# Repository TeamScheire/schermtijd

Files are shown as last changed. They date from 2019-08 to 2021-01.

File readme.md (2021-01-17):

Bekijk het lijstje van alle materiaal: [bill of materials](docs/bill-of-materials.csv)

## Download en installeer raspbian

Via [https://www.raspberrypi.org/downloads/raspbian/](https://www.raspberrypi.org/downloads/raspbian)

De lite versie is voldoende.

Instructies om raspbian op een sd-kaart te zetten staan ook op die pagina.

## Configureren van de sd-kaart

Nadat je raspbian op een SD-kaart hebt, moet je deze nog configureren zodat je via ssh over de wifi aan de raspberry pi kan.

Deze stappen voer je dus uit op je eigen computer, met de sd-kaart ingestoken. 

De commando's zijn voor terminal op mac/linux.

### Navigeer naar de folder van de SD-kaart

```
cd /Volumes/boot
```

### SSH aanzetten

In de rootpartitie van de sd-card:

```
touch ssh
```

### Wifi instellen

```
vim wpa_supplicant.conf
```

Vul volgende gegevens in (vervang de xxxx'n door je eigen SSID en wachtwoord) en sla op

```
ctrl_interface=DIR=/var/run/wpa_supplicant GROUP=netdev
network={
    ssid="xxxxx"
    psk="xxxxx"
    key_mgmt=WPA-PSK
}
```

## Configuratie op de raspberry pi

Nadat je raspberry pi is opgestart, ga je ermee verbinden

```
ssh pi@raspberrypi.local
```

Het standaard wachtwoord is *raspberry*

### locale instellen

```
export LC_ALL="en_GB.UTF-8"
```

### Update van het systeem

```
sudo apt-get update && sudo apt-get -y upgrade
```

### Raspi-config

```
sudo raspi-config
```

Kies: 

- Expand Filesystem
- Change hostname: fastfriendsbox
- Set Timezone

reboot

## nodejs + SQLite

Het scorebord en de activiteiten zitten in een SQLite database met een api errond, geschreven in node.js

```
sudo -s
curl -sL https://deb.nodesource.com/setup_11.x | bash -
exit
sudo apt-get install -y nodejs sqlite3
```

meer info op [https://dev.to/bogdaaamn/run-your-nodejs-application-on-a-headless-raspberry-pi-4jnn](https://dev.to/bogdaaamn/run-your-nodejs-application-on-a-headless-raspberry-pi-4jnn)

### ImageMagic voor de verwerking van de avatars

```
sudo apt-get install imagemagick
```

## Activeren/installeren van de api en frontend

In de folder van de nodejs server alle requirements installeren:

```
cd src
npm install
```

De api starten

```
nodejs server.js
```

## automatisch starten en uitvoeren in de achtergrond van de server

```
cd /lib/systemd/system/
sudo nano doosserver.service
```

Vul deze gegevens in:

```
[Unit]
Description=Doos gpio
After=multi-user.target
 
[Service]
Type=simple
ExecStart=/usr/bin/nodejs /home/pi/src/server.js
Restart=on-abort
 
[Install]
WantedBy=multi-user.target
```

En dan dit uitvoeren:

```
sudo chmod 644 /lib/systemd/system/doosserver.service
chmod +x /home/pi/src/server.js
sudo systemctl daemon-reload
sudo systemctl enable doosserver.service
sudo systemctl start doosserver.service
```

De nodejs server draait nu als een service.

## nginx

Het scorebord draait op een webserver op je raspberry pi, hiervoor moet nginx draaien zodat je het vlot via eender welke browser kan bekijken (zolang die op hetzelfde wifi netwerk verbonden is als je raspberry pi).

```
sudo apt-get install -y nginx
```

configureren van je site:

```
sudo rm /etc/nginx/sites-available/default
sudo nano /etc/nginx/sites-available/default

server {
        listen 80;
        listen [::]:80;

        server_name fastfriendsbox.local;

        root /var/www/;
        index index.html;

        location / {
            proxy_pass http://localhost:3000;
            proxy_http_version 1.1;
            proxy_set_header Upgrade $http_upgrade;
            proxy_set_header Connection 'upgrade';
            proxy_set_header Host $host;
            proxy_cache_bypass $http_upgrade;
        }
}
```

(Her)start de webservice hierna:

```
sudo systemctl restart nginx

```

Nu kan je van eender welk toestel dat op hetzelfde netwerk zit als je raspberry pi surfen naar  [http://fastfriendsbox.local](http://fastfriendsbox.local) om het scorebord te zien.

## Thermal printer

Het is deze [https://www.adafruit.com/product/2751](https://www.adafruit.com/product/2751)

Een volledige handleiding en meer bronnen, [https://learn.adafruit.com/mini-thermal-receipt-printer](hier)

### Draadjes aansluiten

- RX van de printer naar TX van de raspi
- TX van de printer naar RX van de raspi
- GND van de printer naar GND van de raspi

De printer stroom geven (minimaal 1.5A 5v - 9v) via het andere adaptor. De printer trekt veel ampère en dit delen met de raspberry pi is geen goed plan ...

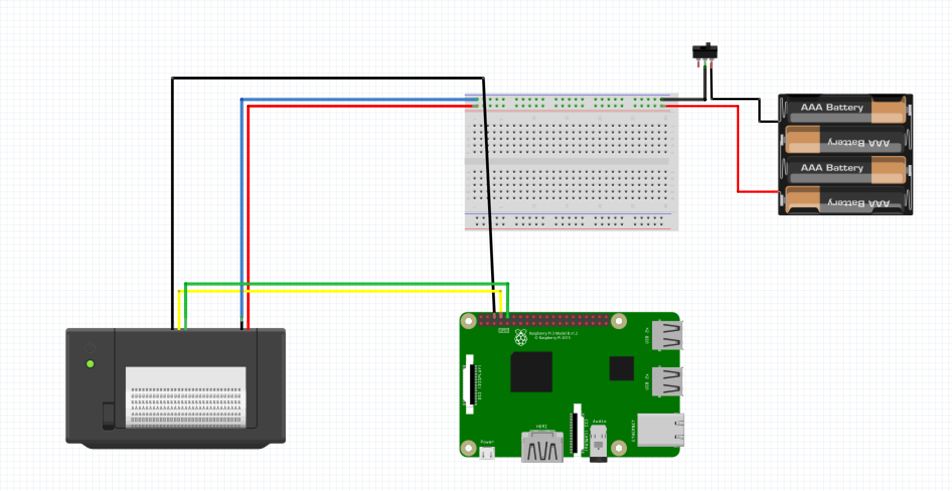
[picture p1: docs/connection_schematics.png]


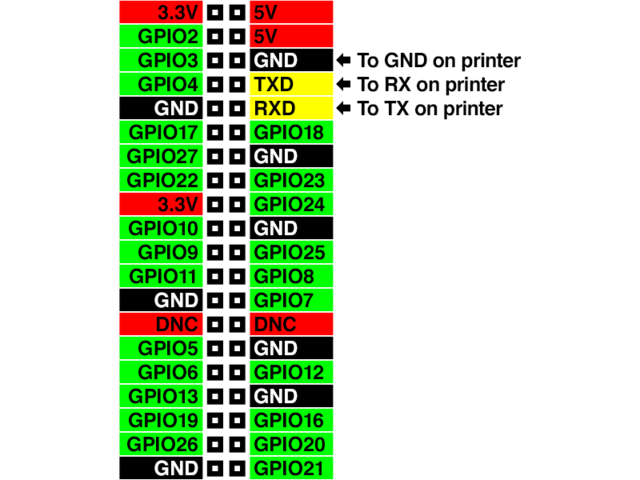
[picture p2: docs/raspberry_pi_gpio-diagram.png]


### activeren over TTL

Eerst configureren zodat we de seriale bus kunnen gebruiken

```
sudo raspi-config
```

Interfacing options > disable the serial console > enable the serial port hardware.

Na reboot, een eerste test:

```
stty -F /dev/ttyS0 9600
echo -e "\\n\\nHallo printertje.\\n\\n\\n" > /dev/ttyS0
```

### repo voor node.js

Om de printer te gebruiken in Node.js, wordt deze library gebruikt: [https://github.com/xseignard/thermalPrinter](https://github.com/xseignard/thermalPrinter).

Via `npm install` heb je deze requirement normaal gezien al geïnstalleerd.

## LED displays

I2C is een protocol waarbij je tot 8 elementen in een bus kan koppelen aan één seriele bus.
Je moet dit protocol eerst activeren op de raspberry pi via raspi-config:

```
sudo raspi-config
```

Daar kies je Interfacing options > I2C > enable (yes)

Voor Python moeten wat paketten/drivers geïnstalleerd worden:

```
sudo apt-get install -y python-smbus i2c-tools build-essential python-dev git python-pil python-pip
git clone https://github.com/adafruit/Adafruit_Python_LED_Backpack.git # voor de 7-segment en de 8x8 matrix
cd Adafruit_Python_LED_Backpack
sudo python setup.py install
cd ..
```

Optioneel (in de uiteindelijke doos zit deze er niet meer in)

```
git clone https://github.com/adafruit/Adafruit_Python_SSD1306.git # voor de oled
cd Adafruit_Python_SSD1306/
sudo python setup.py install

```

Hierna kan je de displays aansluiten en via het volgende commando de adressen checken:

```
sudo i2cdetect -y 1
```

Je krijgt iets in deze aard:

```
pi@schermtijd01:~ $ i2cdetect -y 1
     0  1  2  3  4  5  6  7  8  9  a  b  c  d  e  f
00:          -- -- -- -- -- -- -- -- -- -- -- -- --
10: -- -- -- -- -- -- -- -- -- -- -- -- -- -- -- --
20: -- -- -- -- -- -- -- -- -- -- -- -- -- -- -- --
30: -- -- -- -- -- -- -- -- -- -- -- -- -- -- -- --
40: -- -- -- -- -- -- -- -- -- -- -- -- -- -- -- --
50: -- -- -- -- -- -- -- -- -- -- -- -- -- -- -- --
60: -- -- -- -- -- -- -- -- -- -- -- -- -- -- -- --
70: 70 71 72 -- -- -- -- --
```

Adres 70, 71 en 72 zijn ingebruik

Nog python packet requests installeren om api calls te kunnen doen:

```
pip install requests
```

Starten van python app:

```
python gpio/app.py
```

Stappen staan hier:
[https://learn.adafruit.com/adafruits-raspberry-pi-lesson-4-gpio-setup/configuring-i2c](https://learn.adafruit.com/adafruits-raspberry-pi-lesson-4-gpio-setup/configuring-i2c)

Aansluitingen:
[https://learn.adafruit.com/led-backpack-displays-on-raspberry-pi-and-beaglebone-black/wiring](https://learn.adafruit.com/led-backpack-displays-on-raspberry-pi-and-beaglebone-black/wiring)

python library:
[https://github.com/adafruit/Adafruit_Python_LED_Backpack](https://github.com/adafruit/Adafruit_Python_LED_Backpack)

### Python script as service

```
cd /lib/systemd/system/
sudo nano doos.service
```

Vul deze gegevens in:

```
[Unit]
Description=Doos gpio
After=multi-user.target
 
[Service]
Type=simple
ExecStart=/usr/bin/python /home/pi/gpio/app.py
Restart=on-abort
 
[Install]
WantedBy=multi-user.target
```

En dan dit uitvoeren:

```
sudo chmod 644 /lib/systemd/system/doos.service
chmod +x /home/pi/gpio/app.py
sudo systemctl daemon-reload
sudo systemctl enable doos.service
sudo systemctl start doos.service
```

## PCB voor de doos

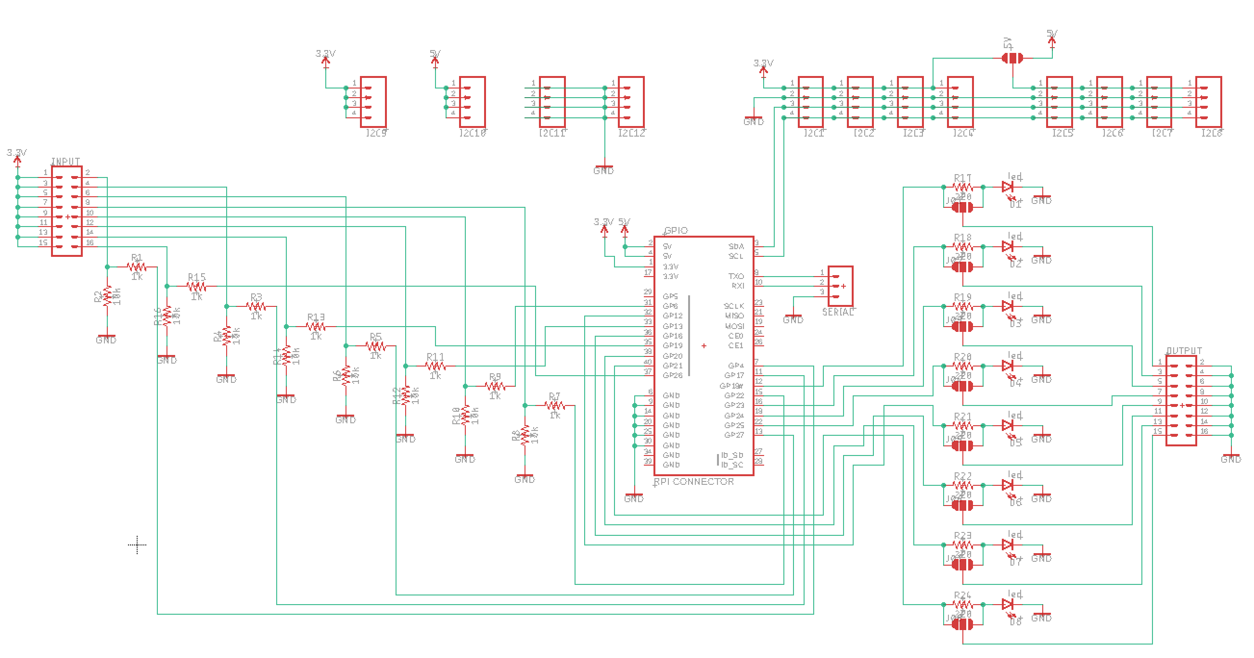
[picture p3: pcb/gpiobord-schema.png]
schema

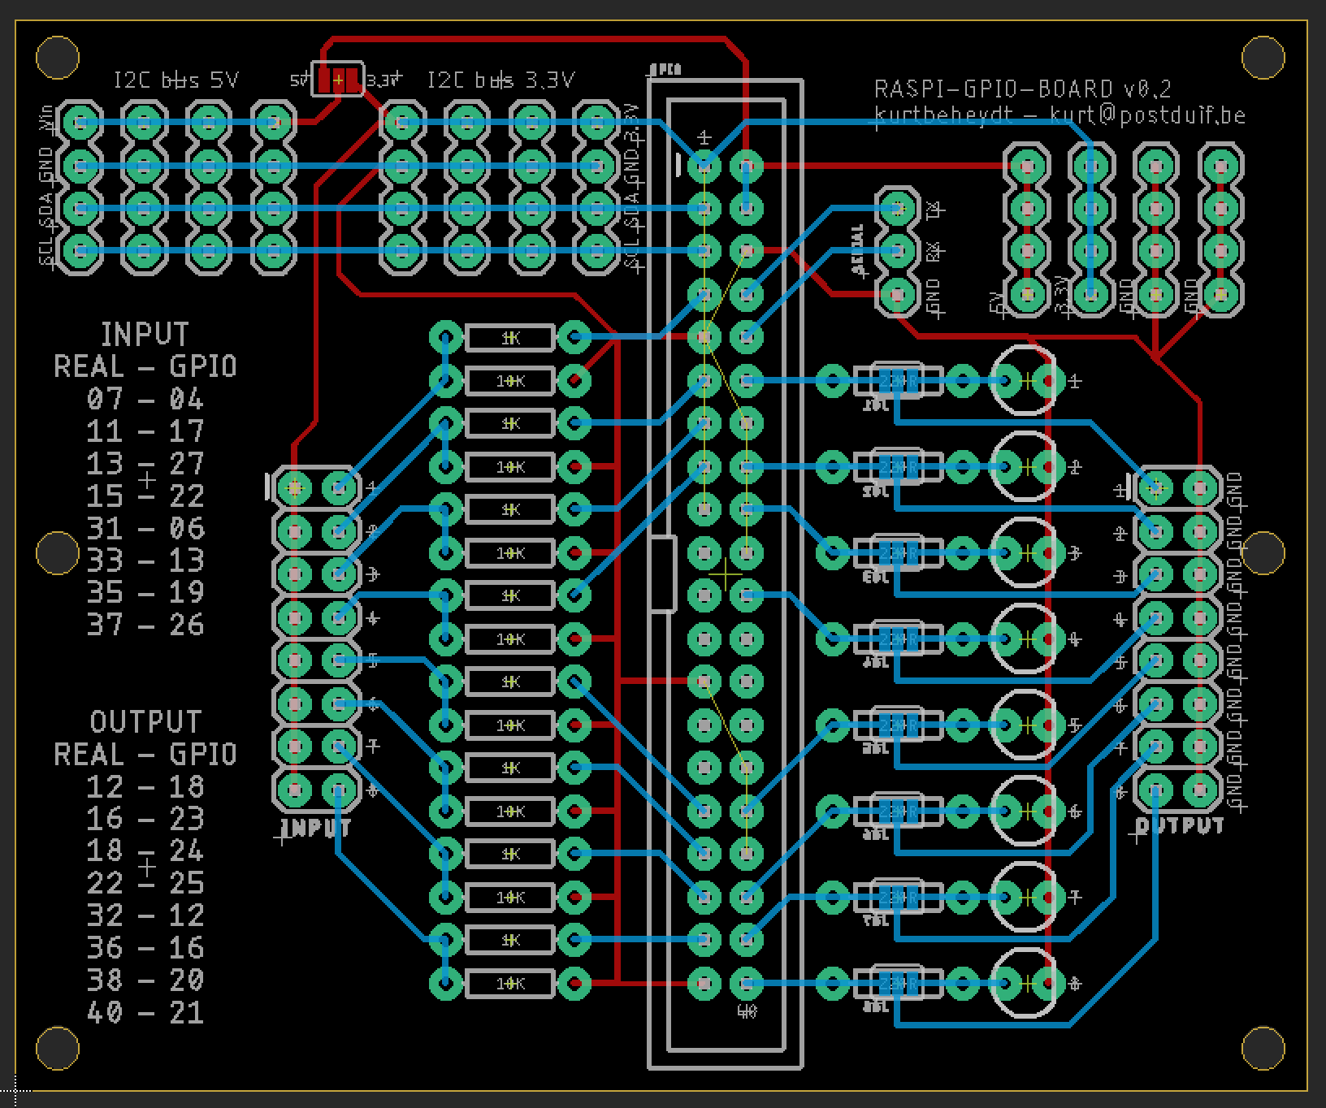
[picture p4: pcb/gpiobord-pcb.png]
pcb


## Extra: raspi als hotspot als geen wifi gevonden wordt
Bron [http://www.raspberryconnect.com/projects/65-raspberrypi-hotspot-accesspoints/158-raspberry-pi-auto-wifi-hotspot-switch-direct-connection](http://www.raspberryconnect.com/projects/65-raspberrypi-hotspot-accesspoints/158-raspberry-pi-auto-wifi-hotspot-switch-direct-connection)

### Installeer de paketten:

```
sudo apt-get install -y hostapd dnsmasq
```

Disable de services bij default:

```
sudo systemctl unmask hostapd
sudo systemctl disable hostapd
sudo systemctl disable dnsmasq
```

### Maak de config file aan:

```
sudo nano /etc/hostapd/hostapd.conf
```

Voeg volgende info in:

```
#2.4GHz setup wifi 80211 b,g,n
interface=wlan0
driver=nl80211
ssid=fastfriendsbox
hw_mode=g
channel=8
wmm_enabled=0
macaddr_acl=0
auth_algs=1
ignore_broadcast_ssid=0
wpa=2
wpa_passphrase=teamscheire
wpa_key_mgmt=WPA-PSK
wpa_pairwise=CCMP TKIP
rsn_pairwise=CCMP
country_code=BE
ieee80211n=1
ieee80211d=1
```

Daarna

```
sudo nano /etc/default/hostapd
```

Verander ```#DAEMON_CONF=""``` in ```DAEMON_CONF="/etc/hostapd/hostapd.conf"```

### Configureer de dns server op de raspberry pi:

```
sudo nano /etc/dnsmasq.conf
```

Vul volgende gegevens in:

```
#AutoHotspot Config
#stop DNSmasq from using resolv.conf
no-resolv
#Interface to use
interface=wlan0
bind-interfaces
dhcp-range=10.0.0.50,10.0.0.150,12h
```
### Configureer de DHCP

```
sudo nano /etc/dhcpcd.conf
```

Voeg onderaan volgende lijn toe:

```
nohook wpa_supplicant
```

### Creëer het hotspot script

```
sudo nano /usr/bin/autohotspot
```

Vul volgende code in:

```
#!/bin/bash
#version 0.95-4-N/HS

#You may share this script on the condition a reference to RaspberryConnect.com 
#must be included in copies or derivatives of this script. 

#A script to switch between a wifi network and a non internet routed Hotspot
#Works at startup or with a seperate timer or manually without a reboot
#Other setup required find out more at
#http://www.raspberryconnect.com

wifidev="wlan0" #device name to use. Default is wlan0.
#use the command: iw dev ,to see wifi interface name 

IFSdef=$IFS
cnt=0
#These four lines capture the wifi networks the RPi is setup to use
wpassid=$(awk '/ssid="/{ print $0 }' /etc/wpa_supplicant/wpa_supplicant.conf | awk -F'ssid=' '{ print $2 }' ORS=',' | sed 's/\"/''/g' | sed 's/,$//')
IFS=","
ssids=($wpassid)
IFS=$IFSdef #reset back to defaults

#Note:If you only want to check for certain SSIDs
#Remove the # in in front of ssids=('mySSID1'.... below and put a # infront of all four lines above
# separated by a space, eg ('mySSID1' 'mySSID2')
#ssids=('mySSID1' 'mySSID2' 'mySSID3')

#Enter the Routers Mac Addresses for hidden SSIDs, seperated by spaces ie 
#( '11:22:33:44:55:66' 'aa:bb:cc:dd:ee:ff' ) 
mac=()

ssidsmac=("${ssids[@]}" "${mac[@]}") #combines ssid and MAC for checking

createAdHocNetwork()
{
    echo "Creating Hotspot"
    ip link set dev "$wifidev" down
    ip a add 10.0.0.5/24 brd + dev "$wifidev"
    ip link set dev "$wifidev" up
    dhcpcd -k "$wifidev" >/dev/null 2>&1
    systemctl start dnsmasq
    systemctl start hostapd
}

KillHotspot()
{
    echo "Shutting Down Hotspot"
    ip link set dev "$wifidev" down
    systemctl stop hostapd
    systemctl stop dnsmasq
    ip addr flush dev "$wifidev"
    ip link set dev "$wifidev" up
    dhcpcd  -n "$wifidev" >/dev/null 2>&1
}

ChkWifiUp()
{
	echo "Checking WiFi connection ok"
        sleep 20 #give time for connection to be completed to router
	if ! wpa_cli -i "$wifidev" status | grep 'ip_address' >/dev/null 2>&1
        then #Failed to connect to wifi (check your wifi settings, password etc)
	       echo 'Wifi failed to connect, falling back to Hotspot.'
               wpa_cli terminate "$wifidev" >/dev/null 2>&1
	       createAdHocNetwork
	fi
}

FindSSID()
{
#Check to see what SSID's and MAC addresses are in range
ssidChk=('NoSSid')
i=0; j=0
until [ $i -eq 1 ] #wait for wifi if busy, usb wifi is slower.
do
        ssidreply=$((iw dev "$wifidev" scan ap-force | egrep "^BSS|SSID:") 2>&1) >/dev/null 2>&1 
        echo "SSid's in range: " $ssidreply
        echo "Device Available Check try " $j
        if (($j >= 10)); then #if busy 10 times goto hotspot
                 echo "Device busy or unavailable 10 times, going to Hotspot"
                 ssidreply=""
                 i=1
	elif echo "$ssidreply" | grep "No such device (-19)" >/dev/null 2>&1; then
                echo "No Device Reported, try " $j
		NoDevice
        elif echo "$ssidreply" | grep "Network is down (-100)" >/dev/null 2>&1 ; then
                echo "Network Not available, trying again" $j
                j=$((j + 1))
                sleep 2
	elif echo "$ssidreplay" | grep "Read-only file system (-30)" >/dev/null 2>&1 ; then
		echo "Temporary Read only file system, trying again"
		j=$((j + 1))
		sleep 2
	elif ! echo "$ssidreply" | grep "resource busy (-16)"  >/dev/null 2>&1 ; then
               echo "Device Available, checking SSid Results"
		i=1
	else #see if device not busy in 2 seconds
                echo "Device unavailable checking again, try " $j
		j=$((j + 1))
		sleep 2
	fi
done

for ssid in "${ssidsmac[@]}"
do
     if (echo "$ssidreply" | grep "$ssid") >/dev/null 2>&1
     then
	      #Valid SSid found, passing to script
              echo "Valid SSID Detected, assesing Wifi status"
              ssidChk=$ssid
              return 0
      else
	      #No Network found, NoSSid issued"
              echo "No SSid found, assessing WiFi status"
              ssidChk='NoSSid'
     fi
done
}

NoDevice()
{
	#if no wifi device,ie usb wifi removed, activate wifi so when it is
	#reconnected wifi to a router will be available
	echo "No wifi device connected"
	wpa_supplicant -B -i "$wifidev" -c /etc/wpa_supplicant/wpa_supplicant.conf >/dev/null 2>&1
	exit 1
}

FindSSID

#Create Hotspot or connect to valid wifi networks
if [ "$ssidChk" != "NoSSid" ] 
then
       if systemctl status hostapd | grep "(running)" >/dev/null 2>&1
       then #hotspot running and ssid in range
              KillHotspot
              echo "Hotspot Deactivated, Bringing Wifi Up"
              wpa_supplicant -B -i "$wifidev" -c /etc/wpa_supplicant/wpa_supplicant.conf >/dev/null 2>&1
              ChkWifiUp
       elif { wpa_cli -i "$wifidev" status | grep 'ip_address'; } >/dev/null 2>&1
       then #Already connected
              echo "Wifi already connected to a network"
       else #ssid exists and no hotspot running connect to wifi network
              echo "Connecting to the WiFi Network"
              wpa_supplicant -B -i "$wifidev" -c /etc/wpa_supplicant/wpa_supplicant.conf >/dev/null 2>&1
              ChkWifiUp
       fi
else #ssid or MAC address not in range
       if systemctl status hostapd | grep "(running)" >/dev/null 2>&1
       then
              echo "Hostspot already active"
       elif { wpa_cli status | grep "$wifidev"; } >/dev/null 2>&1
       then
              echo "Cleaning wifi files and Activating Hotspot"
              wpa_cli terminate >/dev/null 2>&1
              ip addr flush "$wifidev"
              ip link set dev "$wifidev" down
              rm -r /var/run/wpa_supplicant >/dev/null 2>&1
              createAdHocNetwork
       else #"No SSID, activating Hotspot"
              createAdHocNetwork
       fi
fi
```

Maak het script uitvoerbaar:

```
sudo chmod +x /usr/bin/autohotspot
```

### Creëer een service file voor het hotspot script

```
sudo nano /etc/systemd/system/autohotspot.service
```

Vul volgende code in:

```
[Unit]
Description=Automatically generates an internet Hotspot when a valid ssid is not in range
After=multi-user.target
[Service]
Type=oneshot
RemainAfterExit=yes
ExecStart=/usr/bin/autohotspot
[Install]
WantedBy=multi-user.target
```

En activeer de service:

```
sudo systemctl enable autohotspot.service
```

## Meerdere Wifi netwerken instellen

Bewerk deze config file:

```
sudo nano /etc/wpa_supplicant/wpa_supplicant.conf 
```

Vul aan met de SSID en wachtwoorden

```
ctrl_interface=DIR=/var/run/wpa_supplicant GROUP=netdev
update_config=1

network={
    ssid="thuis"
    psk="thuiswachtwoord"
    key_mgmt=WPA-PSK
    id_str="schuis"
}

network={
    ssid="school"
    psk="school-wachtwoord"
    key_mgmt=WPA-PSK
    id_str="school"
}
```

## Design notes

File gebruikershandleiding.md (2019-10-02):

# Fast Friends Box - de handleiding

## Verbinding maken via wifi

Als de fast friends box opgestart is, creëert hij een wifi hotspot.

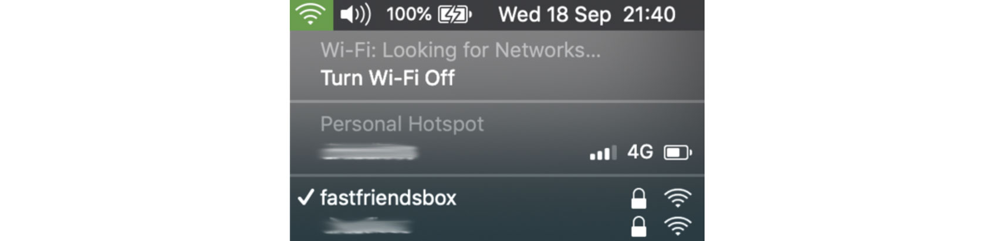
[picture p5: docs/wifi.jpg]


Je kan hier mee verbinden met wachtwoord *teamscheire*.

## Scorebord

Als je met de wifi van de doos verbonden bent, kan je surfen naar het scorebord.

Het adres waar je naar moet surfen is: [http://fastfriendsbox.local](http://fastfriendsbox.local)

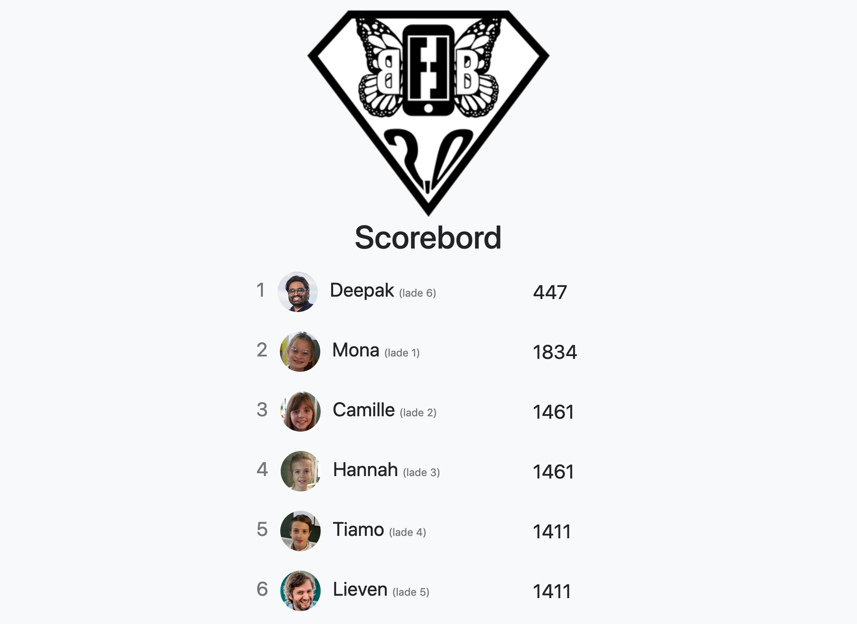
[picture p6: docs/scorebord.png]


## Beheren van de activiteiten

Surf naar [http://fastfriendsbox.local/admin/activiteit.html](http://fastfriendsbox.local/admin/activiteit.html) en je kan activiteiten aanpassen, verwijderen of toevoegen.

Het aantal personen is belangrijk om te bepalen wanneer een activteit door de doos gekozen wordt. Het aantal gsm's dat op dat moment in de doos zit, moet tussen het minimum en maximum aantal liggen van de activiteit.

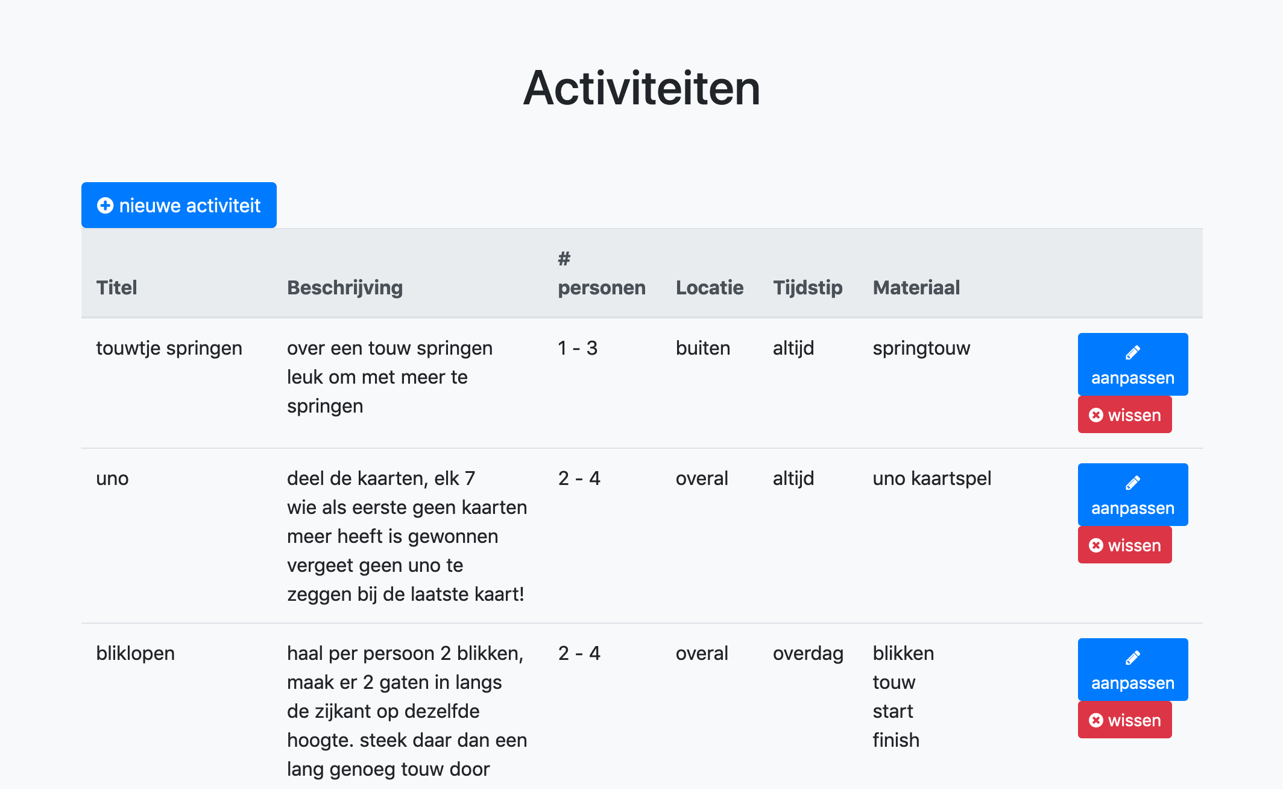
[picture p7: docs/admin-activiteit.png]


## Beheren van de personen (via lades)

Surf naar [http://fastfriendsbox.local/admin/toestel.html](http://fastfriendsbox.local/admin/toestel.html) en je kan de namen van de personen en hun lade aanpassen, de profielfoto's wijzigen en punten aanpassen.

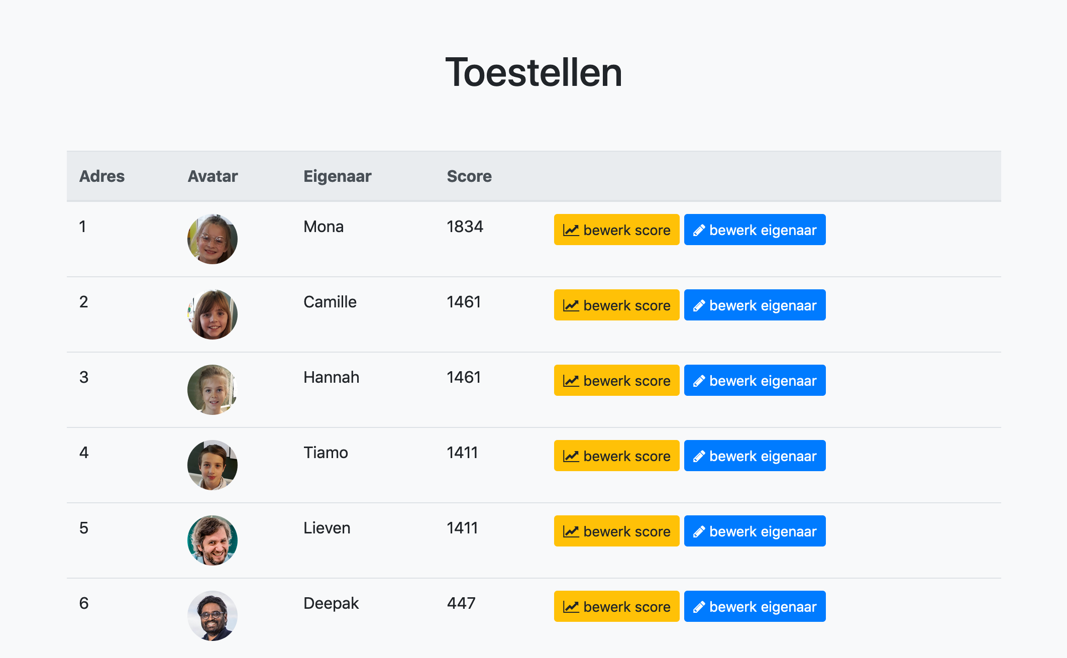
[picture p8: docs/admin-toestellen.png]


### Profielfoto's aanpassen

Klik op de foto van een persoon en je krijgt een scherm om een nieuwe profielfoto te uploaden.

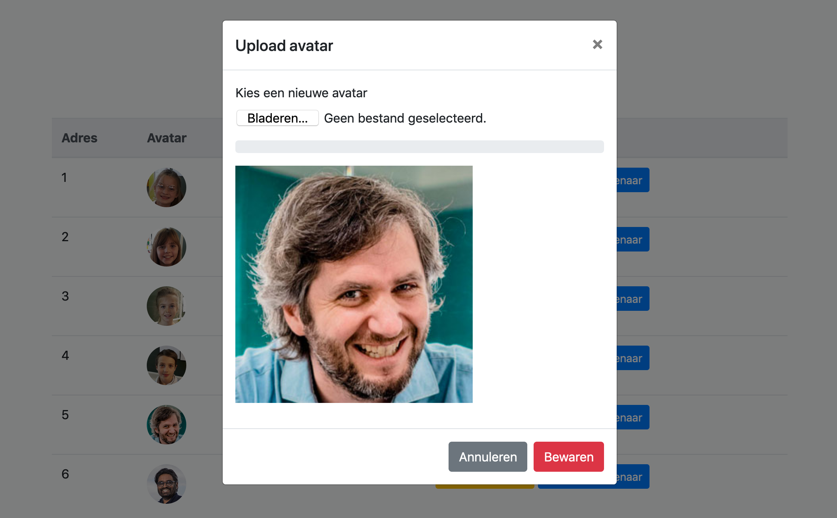
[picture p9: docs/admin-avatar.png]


### Score aanpassen

Klik voor een persoon 'bewerk score'. Je moet nu een extra wachtwoord invullen: *teamscheire* Je krijgt nu een extra scherm waar je punten kan toevoegen, minpunten kan geven of scores kan wissen.

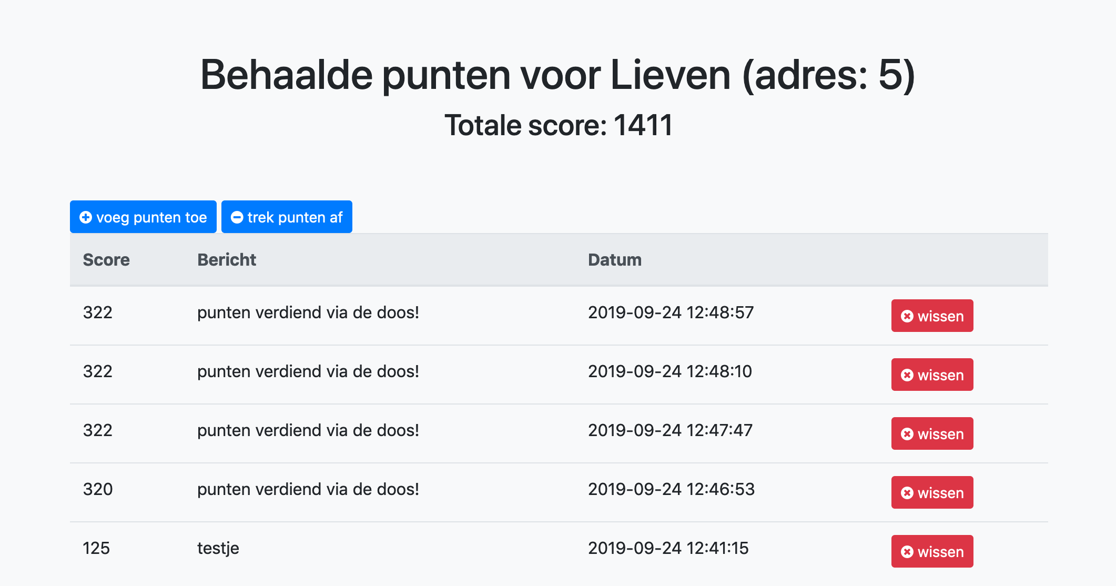
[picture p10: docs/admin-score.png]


## Beheren van de tijdslots

Achter de schermen is er een extra mogelijkheid om per uur te bepalen of er meer of minder punten verdiend kunnen worden als een gsm in de doos zit. Dit gebeurt door per uur een gewicht toe te kennen.

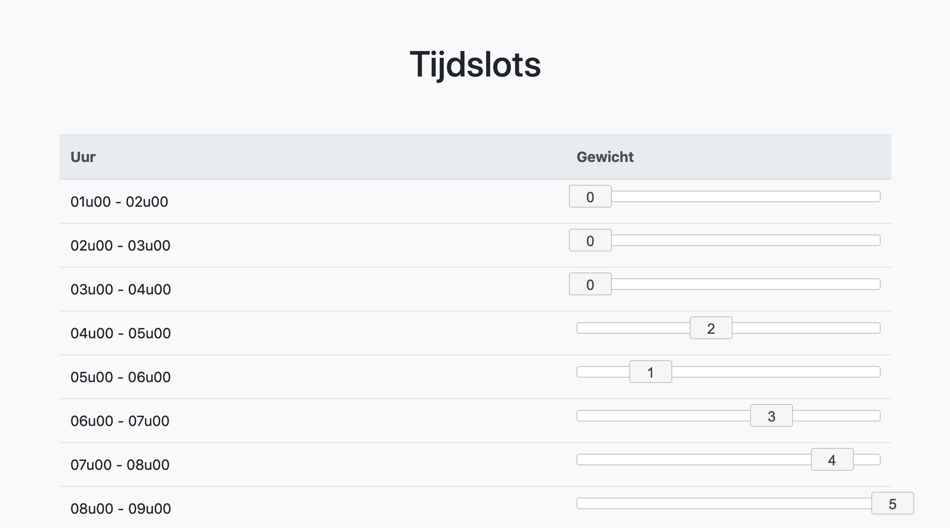
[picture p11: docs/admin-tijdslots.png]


Een gewicht van 0 wil zeggen dat er tijdens dit uur geen punten verdiend worden. Handig bijvoorbeeld voor 's nachts als het niet uit maakt of de gsm in de doos ligt of niet. 

Een gewicht van 5 wil zeggen dat er heel veel punten kunnen verdiend worden tijdens dit uur. Handig voor de piekuren om extra te motiveren om tijdens die uren de gsm in de doos te leggen.

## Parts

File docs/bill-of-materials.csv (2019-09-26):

 | aantal
7 Segment Display Red w/I2C Backpack | 1 | https://www.mouser.be/ProductDetail/Adafruit/1270?qs=sGAEpiMZZMsMyYRRhGMFNq9TrlBKcTqo32ZaxL7MEV4%3D
Adafruit Mini 8x8 Red LED Matrix with Backpack | 2 | https://www.mouser.be/ProductDetail/Adafruit/870
100 V-240 V 6 Port Portable USB Hub | 1 | https://nl.aliexpress.com/item/32596182003.html
Tiny Thermal Receipt Printer | 1 | https://www.mouser.be/ProductDetail/Adafruit/2751
Thermal Paper Roll - 16 long 2.25 | 1 | https://www.mouser.be/ProductDetail/Adafruit/2755
Raspberry Pi 3 model A+ | 1 | https://www.gotron.be/raspberry-pi-3-model-a.html
Industriële voeding Meanwell 50W - 5V / 10A LRS505 | 1 | https://www.gotron.be/industriele-voeding-meanwell-50w-12v-4-2a-lrs505.html
Afdekplaatje 5 polig Meanwell P9,5 | 1 | https://www.gotron.be/afdekplaatje-5-polig-meanwell-p9-5.html
SanDisk Ultra Micro SDHC 16GB | 1 | https://www.bol.com/nl/p/sandisk-ultra-micro-sdhc-16gb-met-adapter/9200000047488161/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
Adafruit Large Arcade LED Red Button | 1 | https://www.mouser.be/ProductDetail/Adafruit/1190
relay + breakout board | 1 | https://nl.aliexpress.com/item/2027291228.html
5v ventilator | 1 | https://www.gotron.be/sunon-ventilator-5vdc-25-x-25-x-10mm-5m-h-16dba.html
Minimicroswitch met hendel | 7 | https://www.gotron.be/minimicroswitch-met-hendel-on-on-5a-125v-3a-250v.html
Sunon Ventilator- 5VDC - 25 x 25 x 10mm -5m3/h - 16dBA | 1 | https://www.gotron.be/sunon-ventilator-5vdc-25-x-25-x-10mm-5m-h-16dba.html
wires with precrimped terminals + crimpconnectors | 1 | https://opencircuit.shop/Product/12605/Wires-with-Pre-crimped-Terminals-50-Piece-Rainbow-Assortment-F-F-24
PCB | 1
Micro-usb kabel | 2
iphone laadkabel | 1
Ledjes 5mm | 6
Ledjes 3mm | 6
weerstand 220Ohm | 12
weerstand 1KOhm | 8
weerstand 10KOhm | 8
female headers (1x20) | 2
male headers (1x8) | 7

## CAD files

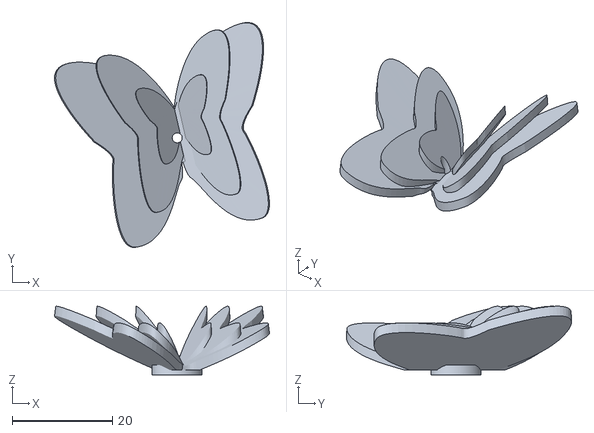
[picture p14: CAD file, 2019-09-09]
doosontwerp/3D-print/vlinder-voetstuk.stl
43.0 x 44.9 x 13.7

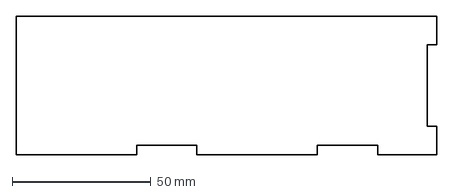
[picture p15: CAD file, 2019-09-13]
doosontwerp/lasercut/3mm-plexi/lade/gsm-schot.dxf
151.5 x 50.0 mm

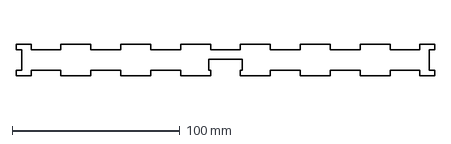
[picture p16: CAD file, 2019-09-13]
doosontwerp/lasercut/3mm-plexi/tussenschot-bovenkant.dxf
250.0 x 19.0 mm

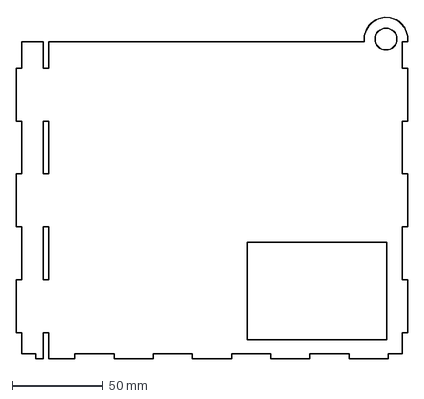
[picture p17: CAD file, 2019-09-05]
doosontwerp/lasercut/3mm/export-rechts.dxf
216.0 x 189.2 mm

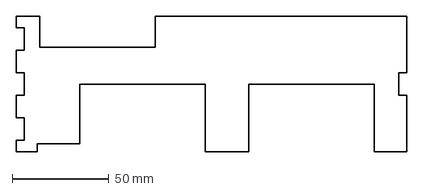
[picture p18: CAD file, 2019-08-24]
doosontwerp/lasercut/4mm/export-tussenschot.dxf
202.0 x 70.0 mm

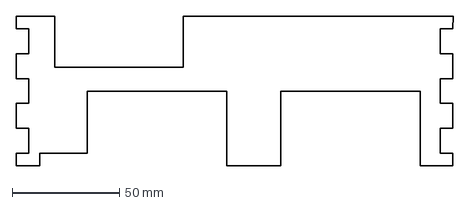
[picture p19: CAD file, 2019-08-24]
doosontwerp/lasercut/6mm/export-tussenschot.dxf
204.0 x 70.0 mm

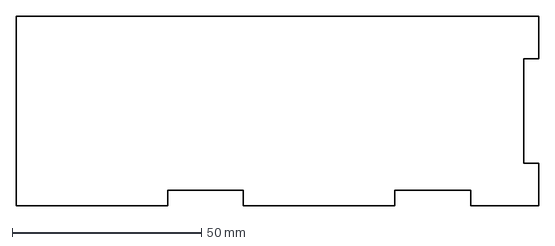
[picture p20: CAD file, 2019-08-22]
doosontwerp/lasercut/export-gsm-schot copy 4.dxf
138.0 x 50.0 mm

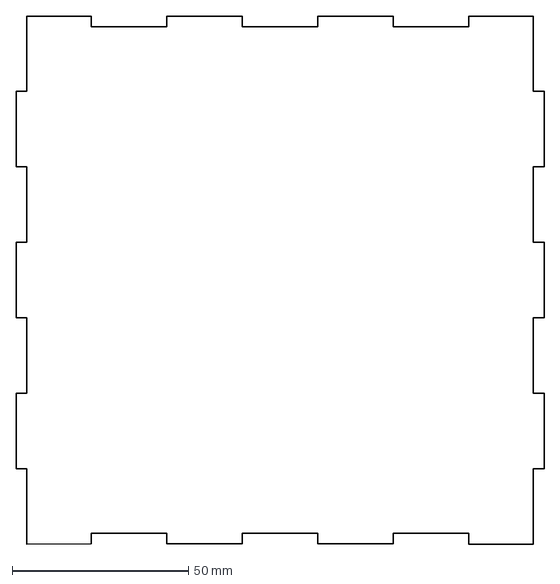
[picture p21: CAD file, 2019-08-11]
lasercut-files/demodoos/export-bottom.dxf
150.0 x 150.0 mm

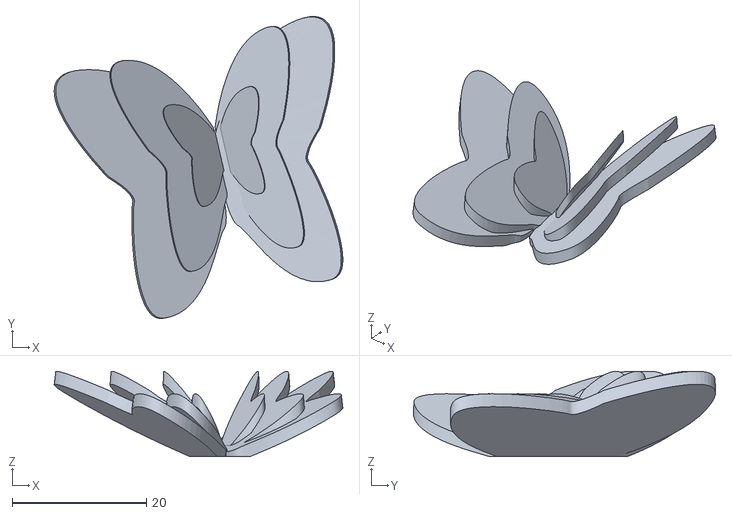
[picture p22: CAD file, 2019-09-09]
doosontwerp/3D-print/vlinder.stl
43.0 x 44.9 x 12.7

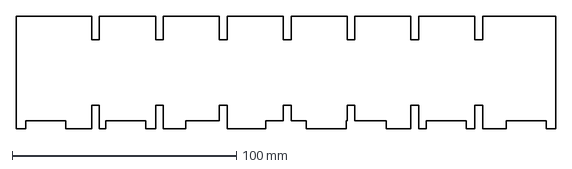
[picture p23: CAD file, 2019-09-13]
doosontwerp/lasercut/3mm-plexi/lade/valse-achterkant.dxf
241.0 x 50.0 mm

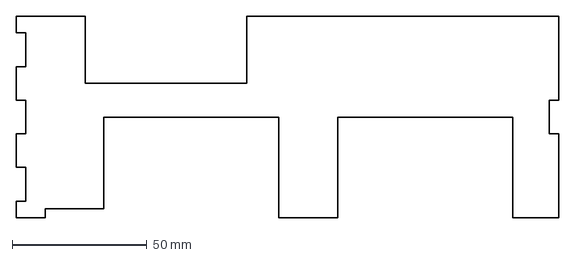
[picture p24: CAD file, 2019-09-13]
doosontwerp/lasercut/3mm-plexi/tussenschot.dxf
201.5 x 75.0 mm

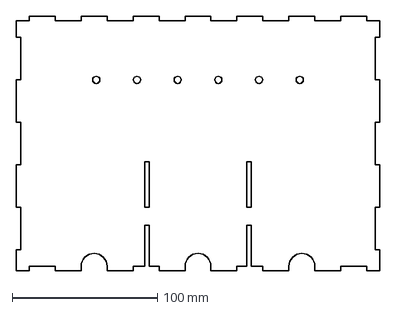
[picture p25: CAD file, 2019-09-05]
doosontwerp/lasercut/3mm/export-tussenschot-voorkant.dxf
250.0 x 175.0 mm

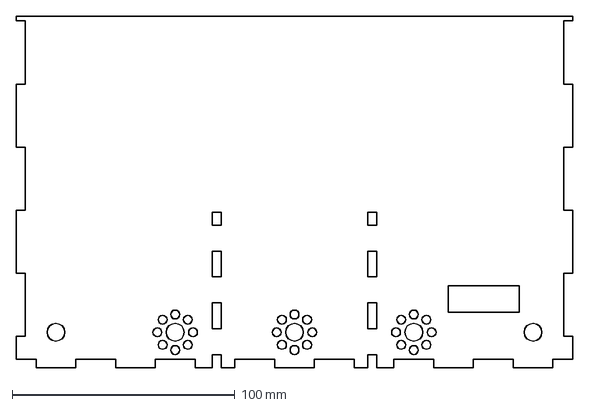
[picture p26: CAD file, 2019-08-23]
doosontwerp/lasercut/4mm/export-achterkant.dxf
250.0 x 158.0 mm

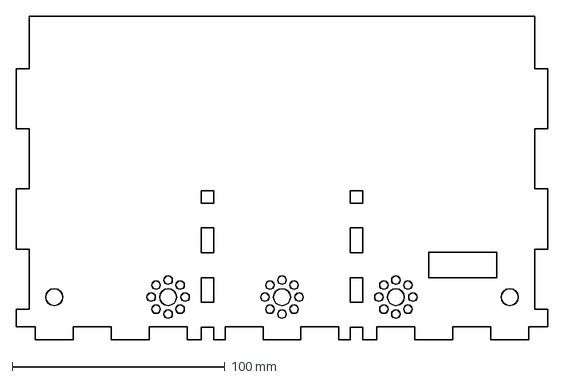
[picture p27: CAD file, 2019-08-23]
doosontwerp/lasercut/6mm/export-achterkant.dxf
250.0 x 152.0 mm

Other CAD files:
doosontwerp/3D-print/gsmslot-verkleiner-4mm.stl
doosontwerp/lasercut/3mm-plexi/lade/valse-bodem.dxf
doosontwerp/lasercut/3mm-plexi/voorkant.dxf
doosontwerp/3D-print/gsmslot-verkleiner-2mm.stl
doosontwerp/3D-print/gsmslot-verkleiner-3mm.stl
doosontwerp/3D-print/microswitch-houder.stl
doosontwerp/3D-print/washer.stl
doosontwerp/lasercut/3mm-plexi/achterkant.dxf
doosontwerp/lasercut/3mm-plexi/bodem.dxf
doosontwerp/lasercut/3mm-plexi/links.dxf
doosontwerp/lasercut/3mm-plexi/rechts.dxf
doosontwerp/lasercut/3mm-plexi/top.dxf
doosontwerp/lasercut/3mm-plexi/tussenschot-voorkant.dxf
doosontwerp/lasercut/3mm/export-achterkant.dxf
doosontwerp/lasercut/3mm/export-bodem.dxf
doosontwerp/lasercut/3mm/export-gsm-schot.dxf
doosontwerp/lasercut/3mm/export-gsm-slot.dxf
doosontwerp/lasercut/3mm/export-links.dxf
doosontwerp/lasercut/3mm/export-top.dxf
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

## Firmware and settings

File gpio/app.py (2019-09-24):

#!/usr/bin/env python

import sched, time, datetime, requests, subprocess
from threading import Thread
import RPi.GPIO as GPIO
from Adafruit_LED_Backpack import SevenSegment
from Adafruit_LED_Backpack import Matrix8x8
import Adafruit_GPIO.SPI as SPI

from PIL import Image
from PIL import ImageDraw
from PIL import ImageFont

displayMode = True

try:
	print('testing I2C')

	# 8X8 led matrix
	matrixRight = Matrix8x8.Matrix8x8()
	matrixRight.begin()
	print('matrixRight loaded')
	matrixLeft = Matrix8x8.Matrix8x8(address=0x72)
	matrixLeft.begin()
	print('matrixLeft loaded')
	# 7-segment display
	display = SevenSegment.SevenSegment(address=0x71, busnum=1)
	display.begin()
	print('SevenSegment loaded')

except Exception as e:
	print('error loading I2C')
	print(e)
	displayMode = False

gsmSlots = [
	# buttonpin, ledpin, toestelnumber
	[13, 16, 1],
	[6, 12, 2],
	[22, 25, 3],
	[27, 24, 4],
	[17, 23, 5],
	[4, 18, 6],
]

doosButton = [19, 20] # gpio poort waarop de knop van het deksel van de doos aangesloten is, status led
activiteitButton = [26, 21] # gpio poort waarop de knop om een activiteit af te drukken op aangesloten is, status led

statusDoosDeksel = 0 # 0 = open, 1 = gesloten
statusPrinting = 0
activeButtons = []
points = 0
currentHour = -1
currentScoreWeight = 0
lastScoreMillis = 0
scoreStartMillis = 0
scoreDelay = 1
stateEyes = 'sad'
stopEyes = False

apiurl = 'http://localhost:3000/api/'
debugMode = 0
eyesThread = False
scoreThread = False

def setup():
	global eyesThread, scoreThread, scoreStartMillis, currentHour
	GPIO.setmode(GPIO.BCM)

	for slot in gsmSlots:
		GPIO.setup(slot[0], GPIO.IN)
		GPIO.setup(slot[1], GPIO.OUT)

	GPIO.add_event_detect(gsmSlots[0][0], GPIO.BOTH, callback = lambda x: handleButton(gsmSlots[0][0], gsmSlots[0][1], gsmSlots[0][2]))
	GPIO.add_event_detect(gsmSlots[1][0], GPIO.BOTH, callback = lambda x: handleButton(gsmSlots[1][0], gsmSlots[1][1], gsmSlots[1][2]))
	GPIO.add_event_detect(gsmSlots[2][0], GPIO.BOTH, callback = lambda x: handleButton(gsmSlots[2][0], gsmSlots[2][1], gsmSlots[2][2]))
	GPIO.add_event_detect(gsmSlots[3][0], GPIO.BOTH, callback = lambda x: handleButton(gsmSlots[3][0], gsmSlots[3][1], gsmSlots[3][2]))
	GPIO.add_event_detect(gsmSlots[4][0], GPIO.BOTH, callback = lambda x: handleButton(gsmSlots[4][0], gsmSlots[4][1], gsmSlots[4][2]))
	GPIO.add_event_detect(gsmSlots[5][0], GPIO.BOTH, callback = lambda x: handleButton(gsmSlots[5][0], gsmSlots[5][1], gsmSlots[5][2]))

	GPIO.setup(doosButton[0], GPIO.IN)
	GPIO.setup(doosButton[1], GPIO.OUT)
	GPIO.add_event_detect(doosButton[0], GPIO.BOTH, callback = lambda x: handledoosButton(doosButton[0], doosButton[1]))

	GPIO.setup(activiteitButton[0], GPIO.IN)
	GPIO.setup(activiteitButton[1], GPIO.OUT)
	GPIO.add_event_detect(activiteitButton[0], GPIO.BOTH, callback = lambda x: handleActiviteitButton(activiteitButton[0], activiteitButton[1]))
	
	eyesThread = Thread(target=animateEyes, args=(stateEyes,))
	eyesThread.start()
	
	resetPoints()

	print('loaded ...')

def millis():
	return int(round(time.time() * 1000))

def animateEyes(dummyvar):
	global stateEyes, stopEyes
	if (displayMode):
		eyesTemplates = {
			'heart': {
				'delay': 250,
				'loop': 2,
				'nextTemplate': 'beatingHeart',
				'stopPrevious': True,
				'sequences': [
					[
						['00000000', '00000000', '00000000', '00011000', '00011000', '00000000', '00000000', '00000000'],
						['00000000', '00000000', '00000000', '00011000', '00011000', '00000000', '00000000', '00000000']
					],
					[
						['00000000', '00000000', '00011000', '00111100', '00111100', '00011000', '00000000', '00000000'],
						['00000000', '00000000', '00011000', '00111100', '00111100', '00011000', '00000000', '00000000']						
					],
					[
						['00000000', '01100110', '11111111', '11111111', '01111110', '00111100', '00011000', '00000000'],
						['00000000', '01100110', '11111111', '11111111', '01111110', '00111100', '00011000', '00000000']
					]
				]
			},
 			'beatingHeart': {
				'delay': 300,
				'loop': 2,
                'nextTemplate': 'happy',
				'stopPrevious': False,
				'sequences': [
					[
						['00000000', '00000000', '00011000', '00111100', '00111100', '00011000', '00000000', '00000000'],
						['00000000', '00000000', '00011000', '00111100', '00111100', '00011000', '00000000', '00000000']						
					],
					[
						['00000000', '01100110', '11111111', '11111111', '01111110', '00111100', '00011000', '00000000'],
						['00000000', '01100110', '11111111', '11111111', '01111110', '00111100', '00011000', '00000000']
					]
				]
			},
 			'happy': {
				'delay': 1500,
				'loop': 0,
                'nextTemplate': 'happy',
				'stopPrevious': False,
				'sequences': [
					[
						['00111000', '01111100', '11111110', '11000110', '11000110', '11111110', '01111100', '00000000'],
						['00011100', '00111110', '01111111', '01100011', '01100011', '01111111', '00111110', '00000000']
					],
					[
						['00000000', '00111000', '01111100', '11111110', '11000110', '11000110', '11111110', '01111100'],
						['00000000', '00011100', '00111110', '01111111', '01100011', '01100011', '01111111', '00111110']
					]
				]
			},     
 			'sad': {
				'delay': 6000,
				'loop': 0,
                'nextTemplate': 'sad',
				'stopPrevious': True,
				'sequences': [
					[
						['00000000', '00000000', '11111110', '11111110', '11000110', '01111100', '00000000', '00000000'],
						['00000000', '00000000', '01111111', '01111111', '01100011', '00111110', '00000000', '00000000']
					],
						[
						['00000000', '00000000', '00000000', '11111110', '11111110', '11000110', '01111100', '00000000'],
						['00000000', '00000000', '00000000', '01111111', '01111111', '01100011', '00111110', '00000000']
					]
				]
			},     
		}

		currentStateEyes = ''
        eyesSequence = 0
        lastMillis = 0
        delay = 0
        currentLoop = 0

        while True:
			if stopEyes:
				print('stopped eye animation')
				matrixLeft.clear()
				matrixLeft.write_display()
				matrixRight.clear()
				matrixRight.write_display()
				break

			if (currentStateEyes):
				try:
					if ((lastMillis + delay) < millis()):
						lastMillis = millis()
						eyes = eyesTemplates[currentStateEyes]['sequences'][eyesSequence]

						matrixLeft.clear()
						matrixRight.clear()
						for x in range(8):
							for y in range(8):
								matrixLeft.set_pixel(x, y, int(eyes[0][x][y]))
								matrixRight.set_pixel(x, y, int(eyes[1][x][y]))
						matrixLeft.write_display()
						matrixRight.write_display()

						sequenceCount = len(eyesTemplates[stateEyes]['sequences'])
						eyesSequence = eyesSequence + 1

						if (eyesSequence >= sequenceCount):
							currentLoop = currentLoop + 1
							eyesSequence = 0
							if ((eyesTemplates[stateEyes]['loop'] > 0) and (currentLoop >= eyesTemplates[stateEyes]['loop'])):
								stateEyes = eyesTemplates[stateEyes]['nextTemplate']
				except:
					print('ledmatrix print error')

			if (stateEyes != currentStateEyes):
				print('new state: ' + stateEyes)
				delay = eyesTemplates[stateEyes]['delay']
				currentStateEyes = stateEyes
				eyesSequence = 0
				currentLoop = 0
				if (eyesTemplates[stateEyes]['stopPrevious']):
					lastMillis = 0

def writeEyes():
	global stateEyes
	if (len(activeButtons) > 0):
		stateEyes = 'heart'
	else:
		stateEyes = 'sad'

def writePoints():
	global points, statusDoosDeksel

	if (displayMode):
		try:
			display.clear()
			if (statusDoosDeksel != 1):
				display.print_number_str('----')
			else:
				display.print_float(points, decimal_digits = 0)
			display.set_colon(False)
			display.write_display()
		except:
			print('writepoints display print error')

def resetPoints():
	global points
	points = 0
	writePoints()

def getScoreHour():
	global currentHour, currentScoreWeight
	now = datetime.datetime.now()
	if (currentHour != now.hour):
		url = apiurl + 'tijdslot/{}'.format(now.hour)
		print('api call: ' + url)
		try:
			response = requests.get(url)
			responsedata = response.json()
			print(responsedata['data'])
			currentHour = now.hour
			currentScoreWeight = responsedata['data']['gewicht']
		except:
			print('api not ready')
	
	return currentScoreWeight

def incrementPoints():
	global points, activeButtons, currentScoreWeight, lastScoreMillis, scoreStartMillis

	scoreDelay = (20 - (2 * currentScoreWeight)) * 1000

	if ((millis() - scoreStartMillis) < 30000):
		scoreDelay = scoreDelay / 2
	if ((millis() - scoreStartMillis) < 20000):
		scoreDelay = scoreDelay / 3
	if ((millis() - scoreStartMillis) < 10000):
		if ((scoreDelay / 4) > 1000):
			scoreDelay = (scoreDelay / 4)
		else:
			scoreDelay = 1000
	if ((millis() - scoreStartMillis) < 5000):
		scoreDelay = 1000

	#print('current millis: ' + str(millis()))
	#print('current scoreStartMillis: ' + str(scoreStartMillis))
	#print('current score delay: ' + str(scoreDelay))

	if (lastScoreMillis + scoreDelay < millis()):
		lastScoreMillis = millis()
		points = points + len(activeButtons)
		#print(points)
		writePoints()

def calculatePoints():
	global activeButtons, statusDoosDeksel
	if ((statusDoosDeksel == 1) and (len(activeButtons) > 0)):
		getScoreHour()
		incrementPoints()
	else:
		resetPoints()

def handleButton(buttonPin, ledPin, toestelNumber):
	global activeButtons, debugMode
	time.sleep(.1)
	buttonStatus = GPIO.input(buttonPin)
	print('gedrukt op pin: ' + str(buttonPin) + ' - status: ' + str(buttonStatus))
	GPIO.output(ledPin, buttonStatus)

	if (buttonStatus):
		if toestelNumber not in activeButtons:
			activeButtons.append(toestelNumber)
	else:
		if toestelNumber in activeButtons:
			activeButtons.remove(toestelNumber)
	writeEyes()

def handledoosButton(buttonPin, ledPin):
	global statusDoosDeksel, points, scoreStartMillis, activeButtons
	time.sleep(.1)
	buttonStatus = GPIO.input(buttonPin)
	GPIO.output(ledPin, buttonStatus)
	print('deksel van de doos is veranderd: ' + str(buttonPin) + ' - status: ' + str(buttonStatus))

	# als van open naar dicht
	if ((statusDoosDeksel == 0) and (buttonStatus == 1)):
		print('Doos is toe gegaan')
		print(activeButtons)
		scoreStartMillis = millis()
		writePoints()

	# als van dicht naar open
	if ((statusDoosDeksel == 1) and (buttonStatus == 0)):
		print('Doos is open gegaan')
		print(activeButtons)
		statusDoosDeksel = buttonStatus
		writePoints()

		if (points > 0):
			data = {
				'score': points,
				'bericht': 'punten verdiend via de doos!',
				'adressen': activeButtons
			}
			url = apiurl + 'toestel/doosscore'
			print('api call: ' + url)
			response = requests.post(url, data=data)
			print(response.json())

	statusDoosDeksel = buttonStatus

def printActiviteit(activeButtons, ledPin):
	global statusPrinting
	print('printing ...')
	cmd = "/usr/bin/nodejs /home/pi/src/print.js {}".format(len(activeButtons))
	result = subprocess.check_output(cmd, shell = True )
	print('done printing')
	statusPrinting = 0
	GPIO.output(ledPin, statusPrinting)

def handleActiviteitButton(buttonPin, ledPin):
	global statusPrinting, activeButtons, statusDoosDeksel
	time.sleep(.1)
	buttonStatus = GPIO.input(buttonPin)
	print('Activiteitknop is ingedrukt: ' + str(buttonPin) + ' - status: ' + str(buttonStatus))
	if ((statusPrinting == 0) and (buttonStatus == 1) and (len(activeButtons) >= 1) and (statusDoosDeksel == 1)):
		print('action to print')
		statusPrinting = 1
		GPIO.output(ledPin, statusPrinting)
		printThread = Thread(target=printActiviteit, args=(activeButtons, ledPin,))
		printThread.start()

def loop():
	while True:
		calculatePoints()
		time.sleep(.5)

def destroy():
	global stopEyes, displayMode, gsmSlots
	try:
		stopEyes = True
		for slot in gsmSlots:
			GPIO.setup(slot[1], GPIO.LOW)
		GPIO.setup(doosButton[1], GPIO.LOW)
		GPIO.setup(activiteitButton[1], GPIO.LOW)
	
		if (displayMode):
			display.clear()
			display.write_display()

		displayMode = False

		GPIO.cleanup()
	except:
		print('I2C error while stopping')

if __name__ == '__main__':
	setup()
	try:
		loop()

	except (KeyboardInterrupt):
		destroy()

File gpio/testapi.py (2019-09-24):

#!/usr/bin/env python

import sched, time, datetime, requests, subprocess

statusDoosDeksel = 0 # 0 = open, 1 = gesloten
statusPrinting = 0
activeButtons = [1]
points = 0
currentHour = -1
currentScoreWeight = 0
lastScoreMillis = 0
scoreStartMillis = 0
scoreDelay = 1
stateEyes = 'sad'
stopEyes = False

apiurl = 'http://localhost:3000/api/'

def setup():
	global scoreStartMillis, currentHour
	currentHour = getScoreHour()
	scoreStartMillis = millis()
	#resetPoints()

	print('loaded ...')

def millis():
	return int(round(time.time() * 1000))

def getScoreHour():
	global currentHour, currentScoreWeight
	now = datetime.datetime.now()
	if (currentHour != now.hour):
		currentHour = now.hour
		url = apiurl + 'tijdslot/{}'.format(currentHour)
		print('api call: ' + url)
		response = requests.get(url)
		responsedata = response.json()
		currentScoreWeight = responsedata['data']['gewicht']
	return currentHour

def incrementPoints():
	global points, activeButtons, currentScoreWeight, lastScoreMillis, scoreStartMillis

	scoreDelay = (20 - (2 * currentScoreWeight)) * 1000

	if ((millis() - scoreStartMillis) < 30000):
		scoreDelay = scoreDelay / 2
	if ((millis() - scoreStartMillis) < 10000):
		scoreDelay = scoreDelay / 3
	if ((millis() - scoreStartMillis) < 5000):
		scoreDelay = 1000

	print('current score delay: ' + str(scoreDelay))

	if (lastScoreMillis + scoreDelay < millis()):
		lastScoreMillis = millis()
		points = points + len(activeButtons)
		print(points)
	    #writePoints()

def doeScore():
	global activeButtons
	activeButtons.append(2)
	activeButtons.append(3)
	activeButtons.append(4)
	activeButtons.append(5)
	activeButtons.append(6)
	print(activeButtons)
	data = {
		'score': 322,
		'bericht': 'punten verdiend via de doos!',
		'adressen': activeButtons
	}
	url = apiurl + 'toestel/doosscore'
	print('api call: ' + url)
	response = requests.post(url, data=data)
	print(response.json())

def loop():
	while True:
		getScoreHour()
		incrementPoints()
		time.sleep(.5)

def destroy():
    print('destroyed')

if __name__ == '__main__':
	setup()
	try:
		doeScore()

	except (KeyboardInterrupt):
		destroy()

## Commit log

2019-08-04 uitleg aansluitingen en setup raspberry pi
    [connection_schematics.fzz]
2019-08-11 demodoos lasercut files
    [export-back.dxf, export-bottom.dxf, export-front.dxf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]
2019-08-13 eerste versie van python app met één button en displays
2019-08-13 offline includes + bugfix
    [printertest.js]
2019-08-15 doos software klaar voor meerdere slots, button voor deksel
2019-08-15 aansluiting op raspi: pcb + schematics
    [connection_schematics.fzz]
2019-08-15 skeleton voor printen van random activiteit
2019-08-17 twee 8x8 matrices voor de ogen + test voor extra oled display
2019-08-19 lasercutfiles - plaatdikte 4mm
    [export-achterkant.dxf, export-bodem.dxf, export-gsm-schot copy 2.dxf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]
2019-08-19 omwisseling van de oogjes
2019-08-20 optimalisatie van de tray in functie van de voetjes voor de schakelaars
    [export-tussenschot copy.dxf, export-tussenschot.dxf, export-valse-bodem.dxf]
2019-08-20 kleine aanpassingen aan ontwerp
    [export-achterkant.dxf, export-back.dxf, export-bodem.dxf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]
2019-08-20 bredere opening onder de valse bodem
    [export-tussenschot copy.dxf, export-tussenschot.dxf]
2019-08-21 parameters voor fusion360
    [parameters_doos.txt]
2019-08-21 test voor thermal printer in nodejs
2019-08-21 printen van activiteiten via knop naar printer + bugfixes
    [app.py, print.js]
2019-08-22 versie 2 van de doos, met extra hulpstukken
    [export-achterkant.dxf, export-bodem.dxf, export-gsm-schot copy 2.dxf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]
2019-08-22 printer print nu ook logo
2019-08-22 prototype voor geanimeerde oogjes in een thread
2019-08-22 stop thread voor de animatie van de oogjes
2019-08-23 versie 3 van het ontwerp van de doos
    [export-achterkant.dxf, export-bodem.dxf, export-gsm-schot copy 5.dxf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]
2019-08-23 verluchtingsgat verplaatst
    [export-achterkant.dxf]
2019-08-23 alle slots aangesloten + bugfixes
    [app.py]
2019-08-24 update van tussenschot
    [export-tussenschot.dxf]
2019-08-25 3 varianten van de gsmslot verkleiner
    [gsmslot-verkleiner-2mm.stl, gsmslot-verkleiner-3mm.stl, gsmslot-verkleiner-4mm.stl]
2019-08-29 remove prototype
2019-08-29 Nieuwe versie van behuizing
    [export-achterkant.dxf, export-bodem.dxf, export-gsm-schot.dxf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]
2019-09-02 logo van de ffb
2019-09-05 update design doos
    [export-achterkant.dxf, export-gsm-schot.dxf, export-links.dxf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]
2019-09-05 printen van echte logo op activiteitenticket
2019-09-09 vlinder als versiering op de doos
    [vlinder-voetstuk.stl, vlinder.stl]
2019-09-13 lasercut dxf for plexi
    [achterkant.dxf, bodem.dxf, gsm-schot.dxf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]
2019-09-13 nieuwe versie van pcb met extra headers en keuze voor outputs om ook via weerstand te gaan
2019-09-26 doc update
    [bill-of-materials.csv]
